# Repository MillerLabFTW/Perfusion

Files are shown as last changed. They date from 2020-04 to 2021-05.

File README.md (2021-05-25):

# Perfusion
### Open-source design for perfusion chambers and related accessories
#### Miller Lab: Physiologic Systems Engineering and Advanced Materials
#### [millerlab.rice.edu](http://millerlab.rice.edu)
###### Project developed by Ian Kinstlinger; revised 04/2020

This repo contains open-source designs for our customizable perfusion chamber system, as detailed in our [2021 paper in Nature Protocols](https://rdcu.be/clcY7). We have included some useful accessories as well which we encourage you to download and print. Please also check out the separate git repo for our [open-source gel flipper](https://github.com/MillerLabFTW/GelFlipper).

To generate perfusion chambers, you will need to first download [OpenSCAD](https://openscad.org/). Our paper linked above provides instructions for programming the chamber design you want, and then subsequently assembling the physical chamber for perfusion experiments. If you want to explore the more advanced functionality of the script for making multiple sets of ports, we have a tutorial for that in the Nature Protocols supplement, also included in this repo for convenience. 

**Bugs and feature requests:** Please help us optimize the chamber design by reporting any bugs you might encounter. Email ian.kinstlinger [at] gmail [dot] com. We may also be able to advise you if you want to add a feature which is not currently supported. We encourage everyone to remix and expand these tools and we would love to see new versions created by the community.

**How to cite:** If you use these resources in a publication, please cite this project as

Kinstlinger, I.S., Calderon, G.A., Royse, M.K. et al. Perfusion and endothelialization of engineered tissues with patterned vascular networks. Nat Protoc (2021). https://doi.org/10.1038/s41596-021-00533-1

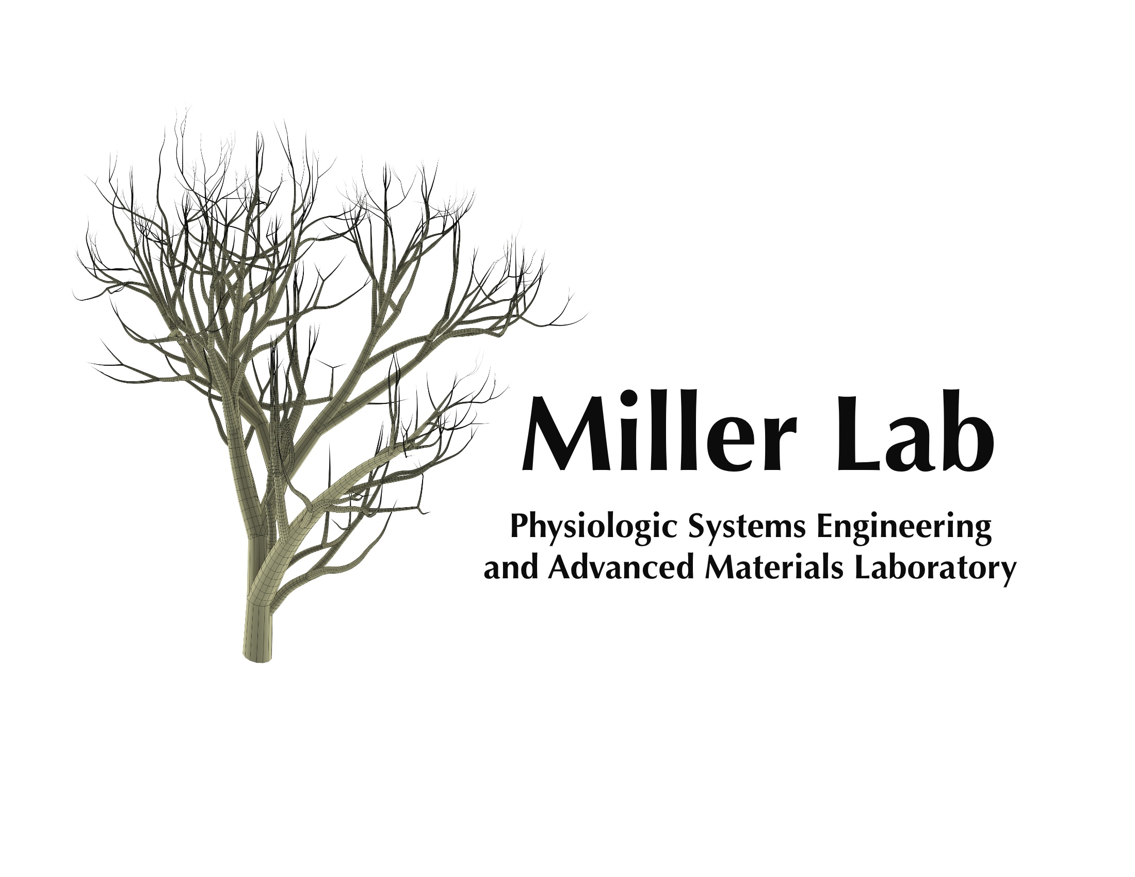
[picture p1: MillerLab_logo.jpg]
MillerLab logo


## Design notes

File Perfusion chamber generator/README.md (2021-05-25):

## Perfusion chamber generator

This is the core OpenSCAD file for generating 3D printable perfusion chambers. Please see detailed instructions in our [Nature Protocols paper](https://rdcu.be/clcY7).

Note 1: Make sure you save the Tip.stl files in the same directory as the .scad file so that the boolean operations work in OpenSCAD!

Note 2: If the Luer tip sizes do not print correctly on your printer, look at the Luer Tip Calibration folder.

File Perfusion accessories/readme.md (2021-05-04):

## Some useful 3D printed accessories for perfusion culture
### Ready-to-print STL files and editable design files provided for each item

### - Offset stands for perfusion chambers
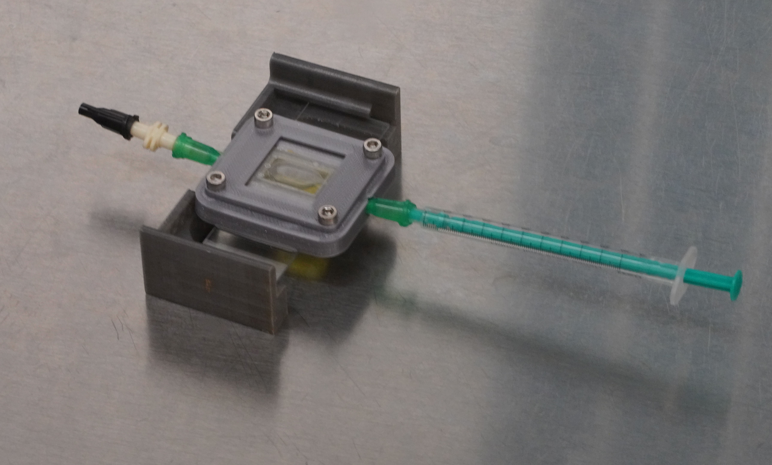
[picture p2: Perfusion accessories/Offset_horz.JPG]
Offset

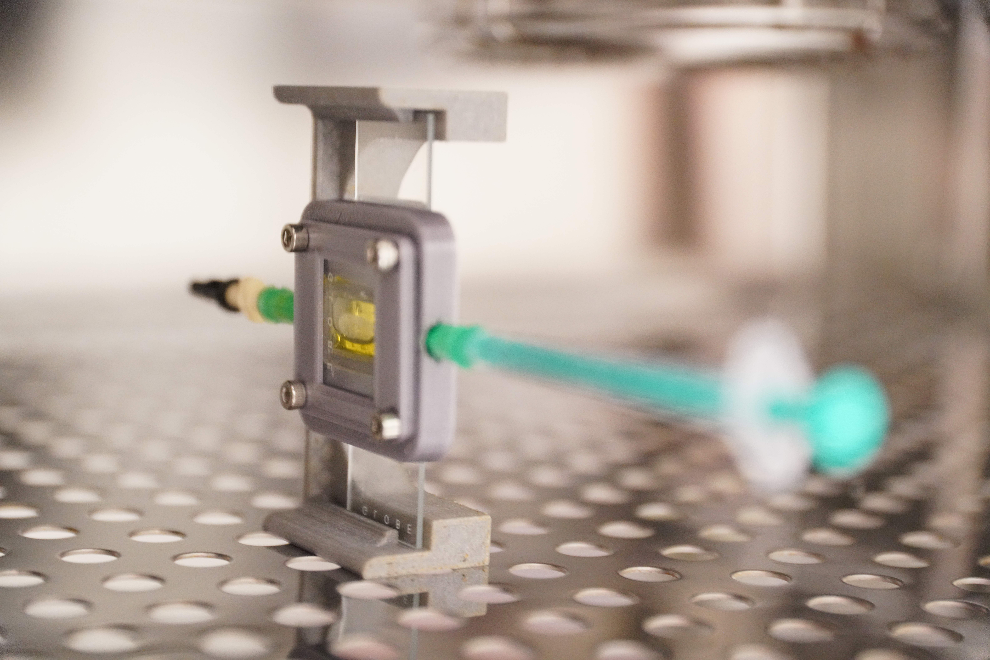
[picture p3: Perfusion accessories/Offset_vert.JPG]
Offset2


This is a simple stand for our perfusion chamber design which positions the inlet of a thin gel high enough above the bench/shelf to connect a sterile filter upstream. The design also makes it easy to handle and transport the chambers, and to rotate them around for endo seeding.

### - Vertical gel stand
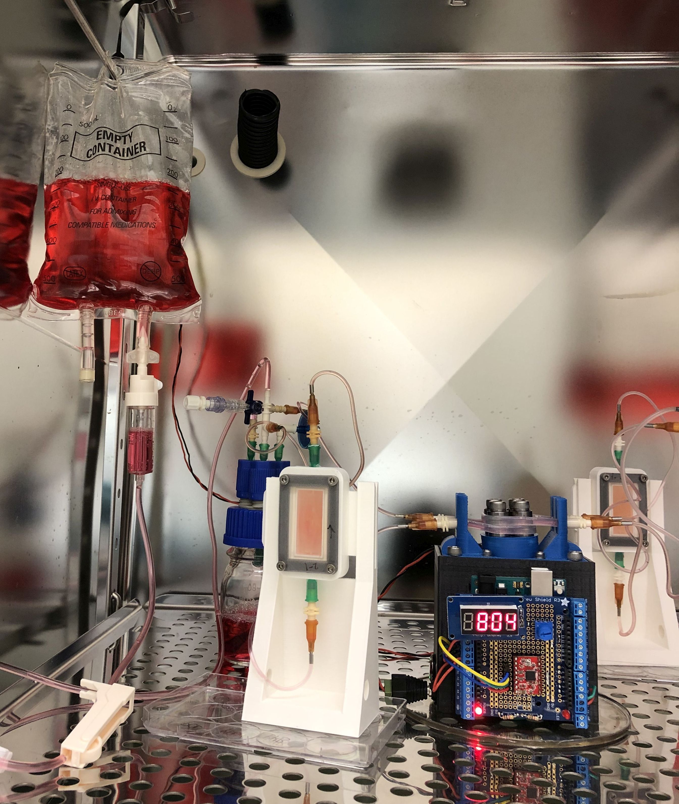
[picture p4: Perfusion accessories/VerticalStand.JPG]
Vert stand


Vertical perfusion can give more even fluid transport through gels with highly branched vascular networks. This vertical stand fits our perfusion chamber design if the "fins" option is enabled.

### - Media bag hanging racks

We have built custom media bag racks from aluminum T-slot extrusion (available from Misumi or McMaster-Carr, and others). The design depends on the model of incubator where you need to install it. We have one incubator with solid shelves and perforated walls, where we use rack that mounts to the wall. 

Many incubators have perforated shelves, for which we make a standing rack out of three pieces of extrusion in a U shape (hold together with corner brackets). To mount, we have feet which can be inserted into the shelf perforations. 

The two designs given here may not fit your incubator exactly, but hopefully will give you an idea of what can work.

Parts list for rack:
- 20x20 mm T-slot aluminum extrusions (e.g. McMaster-Carr 5537T514)
- Corner brackets for 20mm T-slot extrusion (e.g. McMaster-Carr 5537T441)
Some brackets come with fasteners. If you need separate fasteners:
- M5 T-slot nuts (e.g. McMaster-Carr 90510A232)
- M5x8 mm bolts (e.g. McMaster-Carr 91292A191)

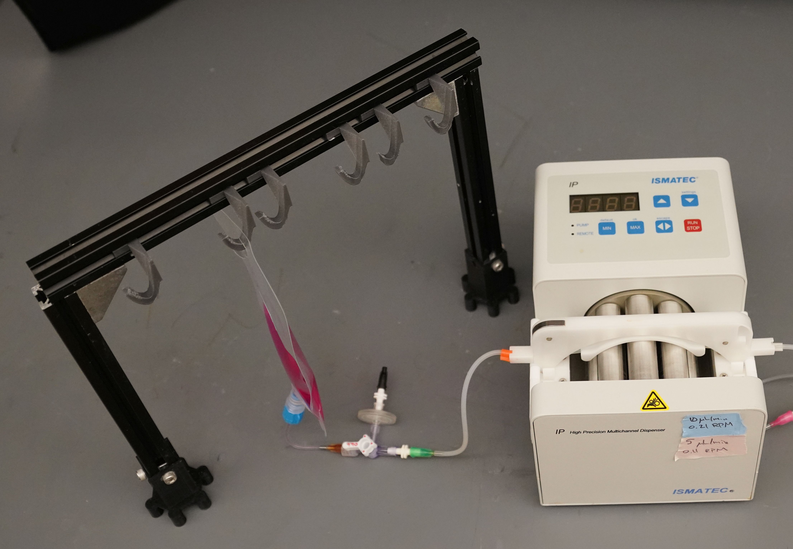
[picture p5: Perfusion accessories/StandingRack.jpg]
StandingRack


How the rack's feet can be mounted in an incubator:
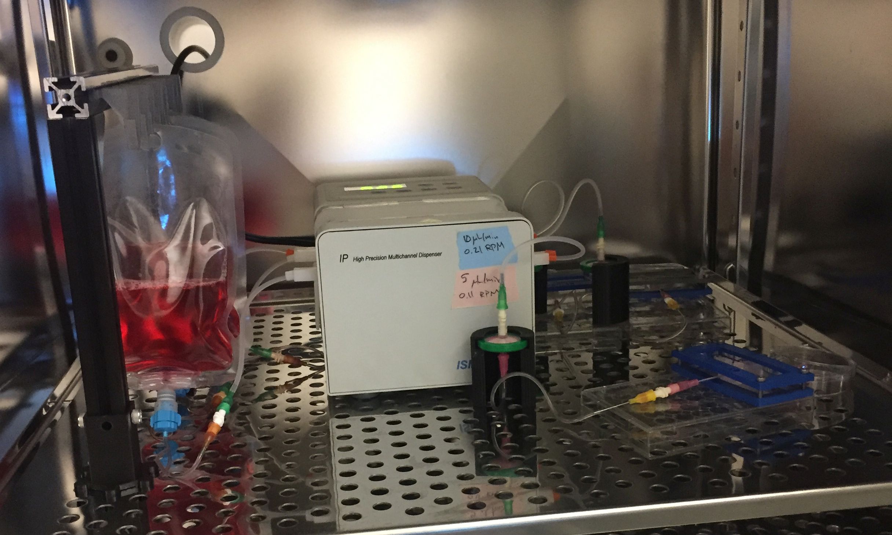
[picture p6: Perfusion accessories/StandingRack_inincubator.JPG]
StandingRack


Hanging version; feet insert into wall:
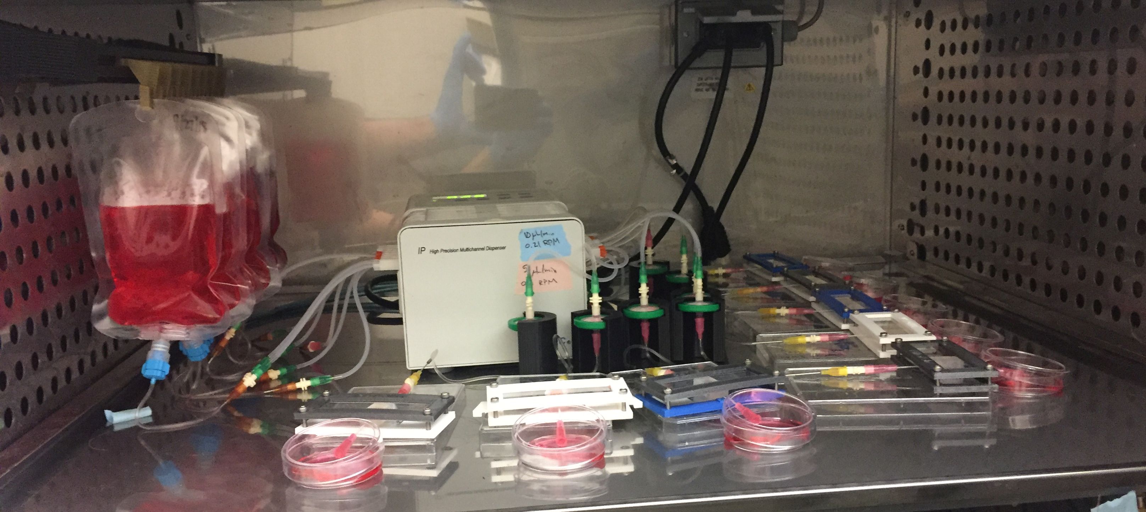
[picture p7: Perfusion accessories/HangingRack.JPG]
HangingRack


### - Media bag hanging hooks

A hanging rack isn't much use without hooks! We have a simple 3D printed hook design which can slide along the tracks of the T-slot extrusion, pictured above.

### - Microscope adapters for imaging perfusion chambers

We include one adapter for a standard multiwell plate format which should fit any standard microscope with a plate imaging stage. We also include a larger adapter for the entire stage footprint of a Nikon Ti-E inverted microscope. With the provided SolidWorks files, this can be modified to fit other brands of microscopes.

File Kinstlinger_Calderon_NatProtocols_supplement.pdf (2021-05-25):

# Supplementary information

# Perfusion and endothelialization of

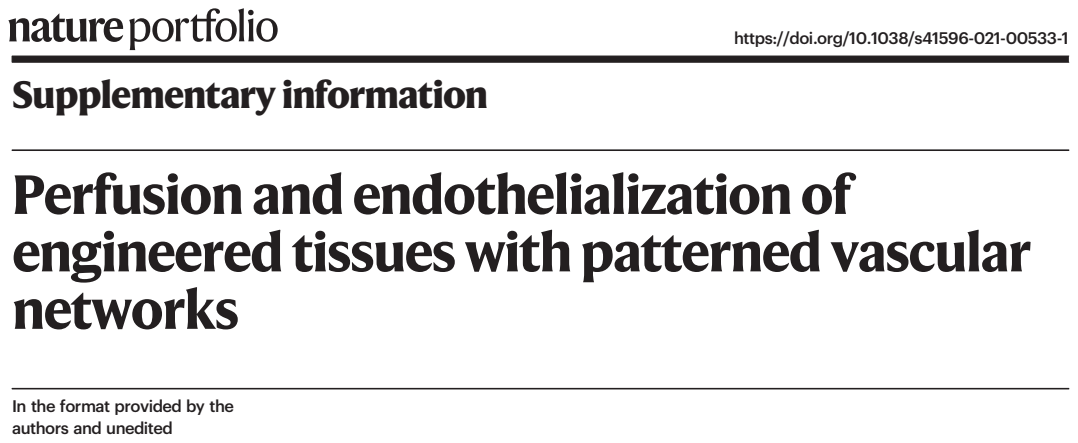
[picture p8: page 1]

https://doi.org/10.1038/s41596-021-00533-1

engineered tissues with patterned vascular
networks

In the format provided by the
authors and unedited

### Supplementary information for

### Perfusion and endothelialization of engineered tissues with patterned vascular networks

Ian S. Kinstlinger¹*, Gisele A. Calderon¹*, Madison K. Royse¹

, A. Kristen Means¹
,

Bagrat Grigoryan¹

, and Jordan S. Miller¹†

1 Department of Bioengineering, Rice University, Houston, TX, USA

* Authors contributed equally

† Corresponding author, email: jmil@rice.edu

Supplementary Manual: Customization of perfusion chambers with multiple sets of inlets and outlets

In the main manuscript, we outline how our scriptable perfusion chambers can be easily modified to accommodate gels of various dimensions or incorporate additional features such as PDMS anchors and gaskets. Here we describe a more advanced set of options to specify the positions of an arbitrary number of ports for catheterizing the gel. These options are useful for changing the position of the default single inlet and single outlet, and also for adding new sets of ports which may facilitate experiments with multivascular networks or side-by-side configurations of perfusable channels.

The nomenclature for specifying port locations relies on an openSCAD variable called portsVector. portsVector is a vector of vectors and is declared between lines 88-98 of the R2 version of the perfusion chamber generator script. By default, the definition of portsVector is:

PortsVector = [

[0, 0, 0, TipBooleanDist, NeedleGauge, 1]

];

Generating a chamber with this default portsVector results in the placement of a single inlet and single outlet on the short sides of the chamber (Fig. 1a). Each port is exactly centered on its face in the default configuration. Note that TipBooleanDist and NeedleGauge are user-defined parameters in the code, which have default values of 11 and 18 (GA), respectively.

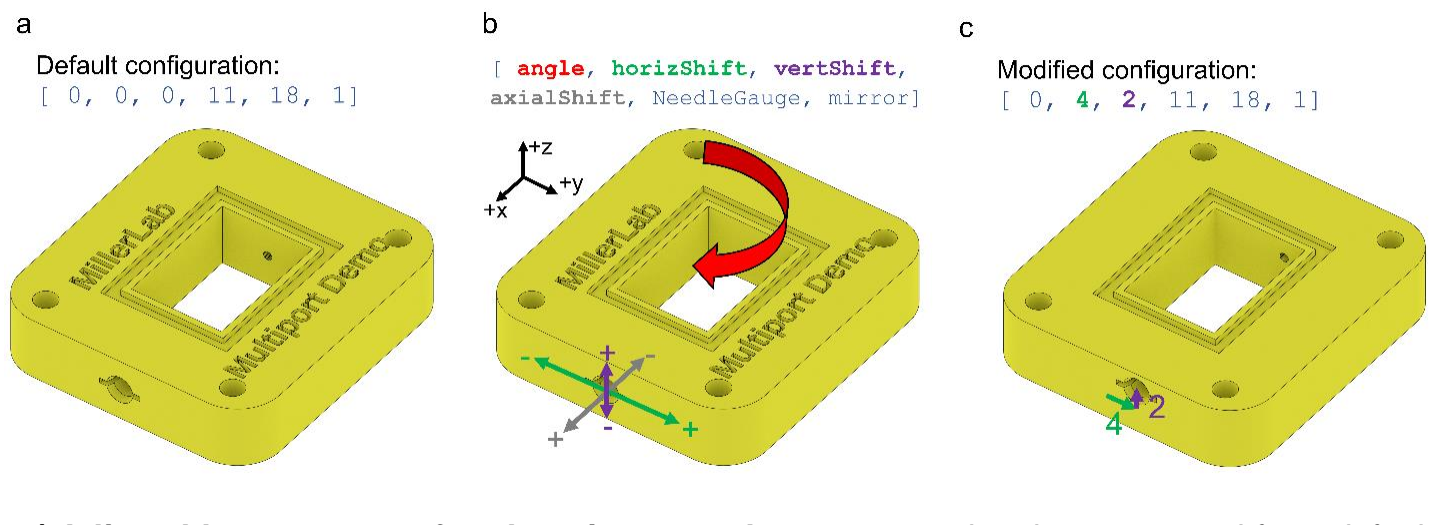
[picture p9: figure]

Figure 1 | Adjustable parameters for changing port placement. a, chamber generated from default
portsVector settings. b, Annotation of rotation and translation functions available for port placement. c, Annotated example of translating an inlet/outlet port pair to an off-center position.

We can begin to understand the syntax for generating custom ports by adjusting the vector elements in the default port. Each vector within PortsVector has six elements which specify the geometry of the tip, as described below:

PortsVector = [

[ angle, horizShift, vertShift, axialShift, NeedleGauge, mirror]

];

Fig. 1b illustrates the effect of the first four elements in terms of the inlet position. Fig. 1c demonstrates the translation of the inlet port by altering elements 2 and 3, horizShift and
vertShift.

Adjust element 1 to change which side of the chamber the port is added on. The default position is 0 degrees, which corresponds to short side in the -x direction. Use 90 degrees to get a port placed on the long side (in the -y direction). 180 gives a port on the short side in the +x direction, and so on. Values of element 1 not in 90 degree increments are allowed, but should only be used in the rare case that the vascular network itself does not form a right angle with respect to the gel. Fig. 2 provides a visual recap of the angle selection. Note: when combining an angle setting with a horizShift, note that the direction of the horizontal shift will always be in the +x or +y direction.

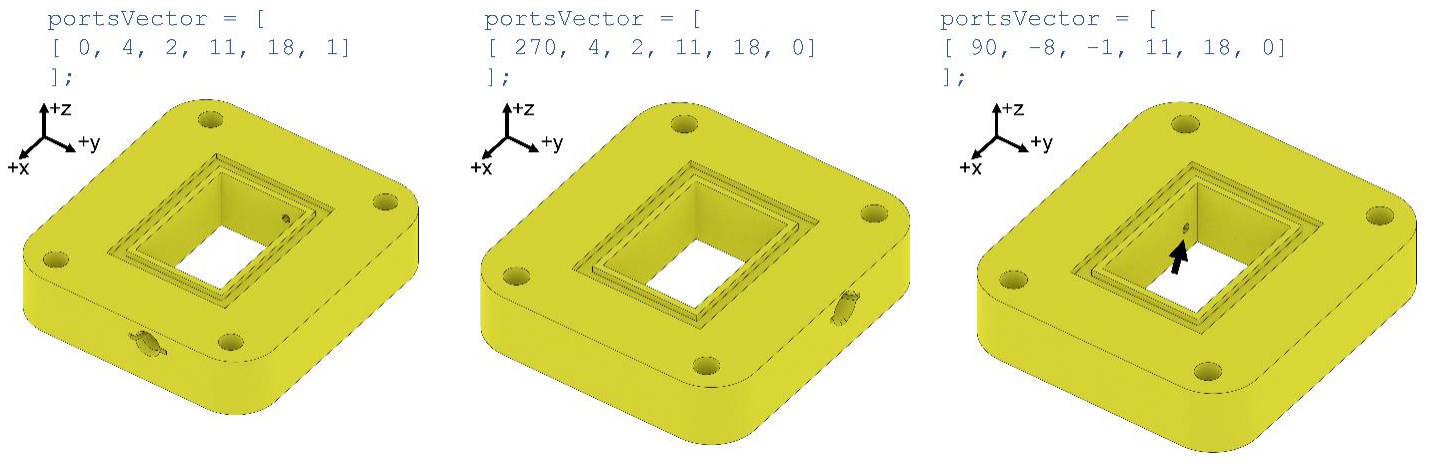
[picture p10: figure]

Figure 2 | Rotation angle parameter for port placement. Examples highlight the effects of adjusting
element 1 in portsVector to describe the face where the port is placed.

Element 4, axialShift, controls where the cavity for the catheter tip is positioned relative to the chamber edge. This has the effect of controlling how far the tip will protrude into the chamber interior, and thus, into the gel. The correct value will depend on your catheter tip length and how far you want it to stick into the inlet. A larger value of axial shift will push the catheter tip out of the central cavity; a smaller value will make it stick further into the gel (see Fig. 3a). By default, axialShift is set to the openSCAD variable TipBooleanDist, which has default value is 11, an empirically determined value which has worked well in our studies.

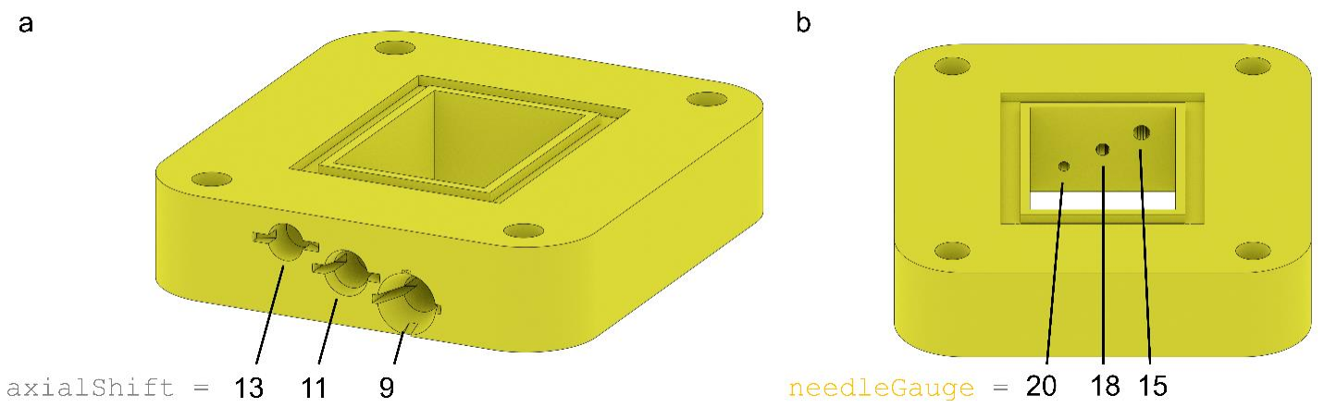
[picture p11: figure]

Figure 3 | Axial port positioning and tip diameter. a, Three example ports demonstrate the effect of
the axialShift parameter on the geometry of the cavity where the Luer tip is wedged into the chamber. b, An array of three ports highlights the three Luer tip port sizes available by default within the perfusion generator script, selected with needleGauge.

Element 5, needleGauge, is simply the gauge of catheter tip you want to insert through the port. 15, 18, and 20 gauge needles have been optimized extensively within the code and are the pre-loaded size options (Fig. 3b). The default is 18 gauge.

Element 6, mirror, allows you to use a single entry in portsVector to define not a single port, but a pair of ports, e.g. an inlet and outlet. For a tip geometry described by portsVector elements 1-5, mirror specifies the number of axes across which the port should be reflected. mirror can be assigned the value 0, 1, 2, or 3, the effects of which are shown in Fig. 4. mirror = 0 creates just one port, mirror > 0 creates a pair of ports by reflecting the specified port across 1, 2, or 3 axes. The first axis of reflection always places the reflected port on the opposite side of the chamber; the second and third axes reflect the port horizontally and vertically across the same side of the chamber.

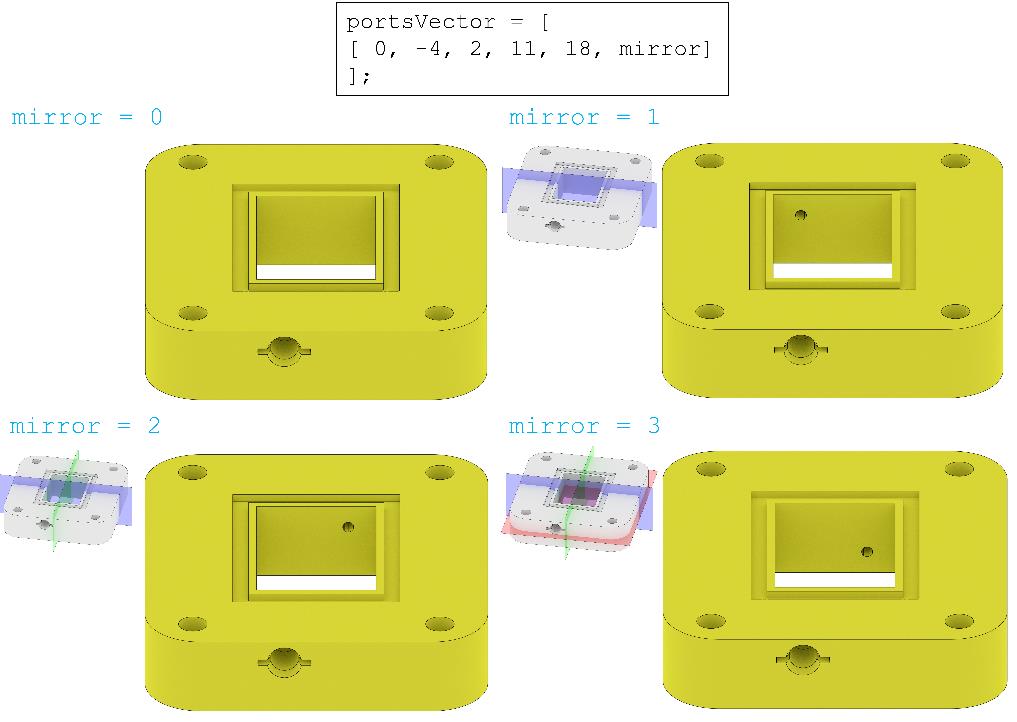
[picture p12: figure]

Figure 4 | Mirroring tips to create pairs of inlets/outlets. The resulting geometry is shown for each
possible value of mirror applied to the same base port configuration. Chambers are viewed from the -x direction.

Now that we have described how the 6 elements of each vector entry in portsVector can be used to control port placement, we can begin adding multiple sets of ports by adding additional vectors within portsVector. Fig. 5 shows some examples which combine sets of ports. Note that vectors within portsVector must be comma-separated, and that lines of code within openSCAD can be commented out with a // to suppress them.

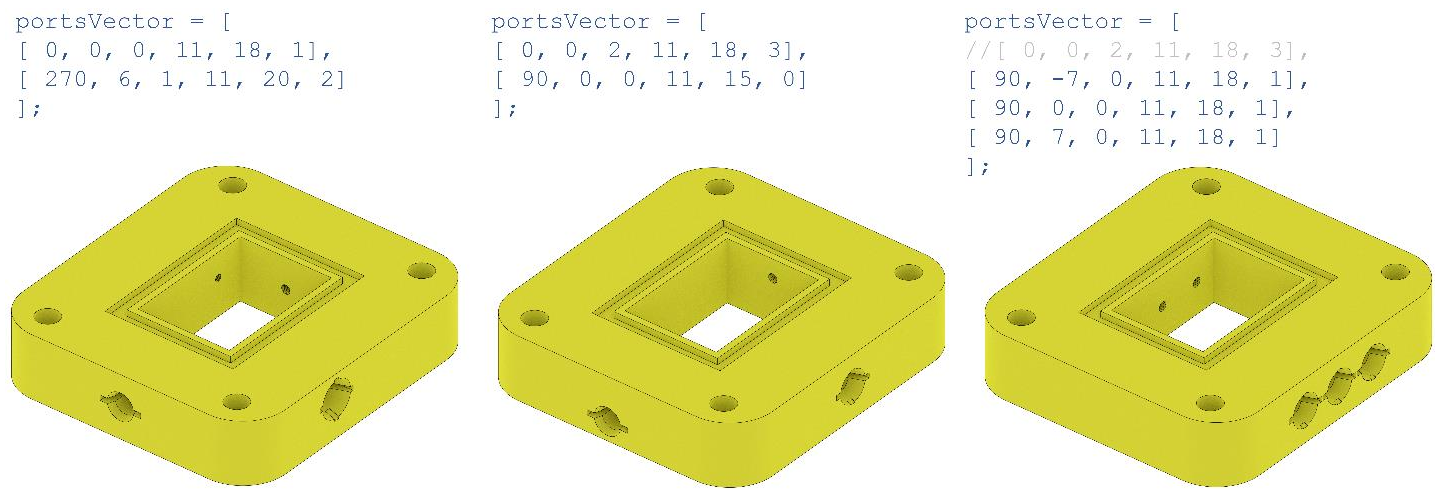
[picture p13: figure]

Figure 5 | Examples of configurations with multiple ports. We illustrate examples with 4, 3, and 6
total inlet/outlet ports to highlight the flexible configurations available.

Finally, we note that the other features of the perfusion chamber generator are fully compatible with the repositioning and addition of ports. In particular, if needle gaskets and PDMS anchor traps are enabled, these features will be automatically repositioned as needed when ports are relocated. We demonstrate these features in Fig. 6.

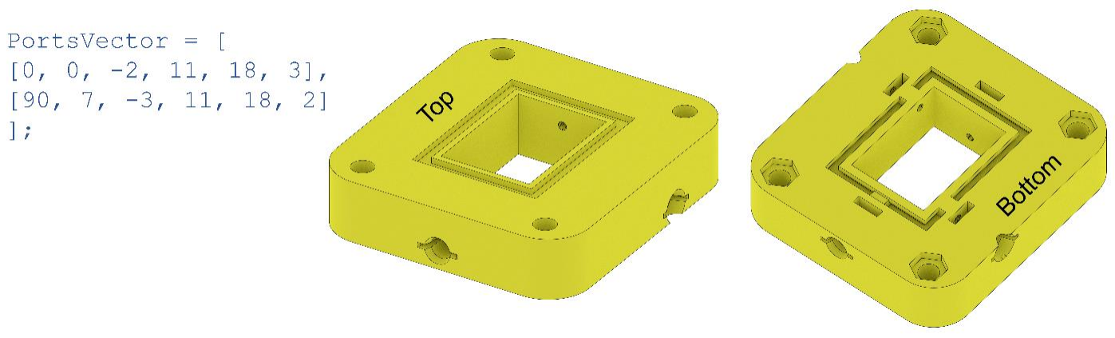
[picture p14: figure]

Figure 6 | PDMS trap features adapted to reconfigured ports. In this example, needle molds and
PDMS anchor traps are enabled to create a stronger and longer-lasting airtight seal (see Fig. 2 in main Protocol). Note that when ports are added or rearranged, the needle molds follow the positions of the ports. As needed, a gap is created in the PDMS anchor trap perimeter for a Luer tip to pass through.

Supplementary figures

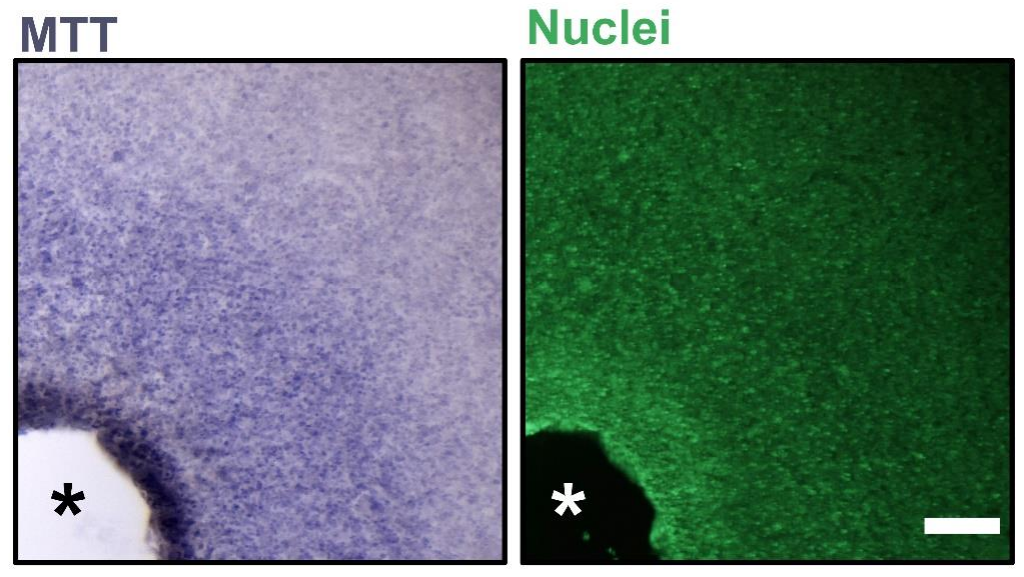
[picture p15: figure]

Figure S1 | Radial gradients of metabolic activity and cell density form around a perfused vessel.
In an initially homogeneous population of HepG2 cells (ATCC Cat# HB-8065, RRID:CVCL_0027; 60e6 cell/mL), we observed the development of radially inhomogeneous patterns of metabolic activity (MTT stain) and proliferation (using nuclear intensity as a proxy for number of cells) after three days of perfusion (25 µL/min) using the protocols described in stages 1 and 3. The methods used and the quantification and analysis of these gradient patterns are fully described in our previous publication¹
. Scale bar = 200
μm; gels are 2 wt% low-melt agarose; asterisk marks the lumen. Images were obtained using a SteREO Discovery.V8 stereoscopic microscope (Zeiss) equipped with EOS 5DSR color camera (Canon).

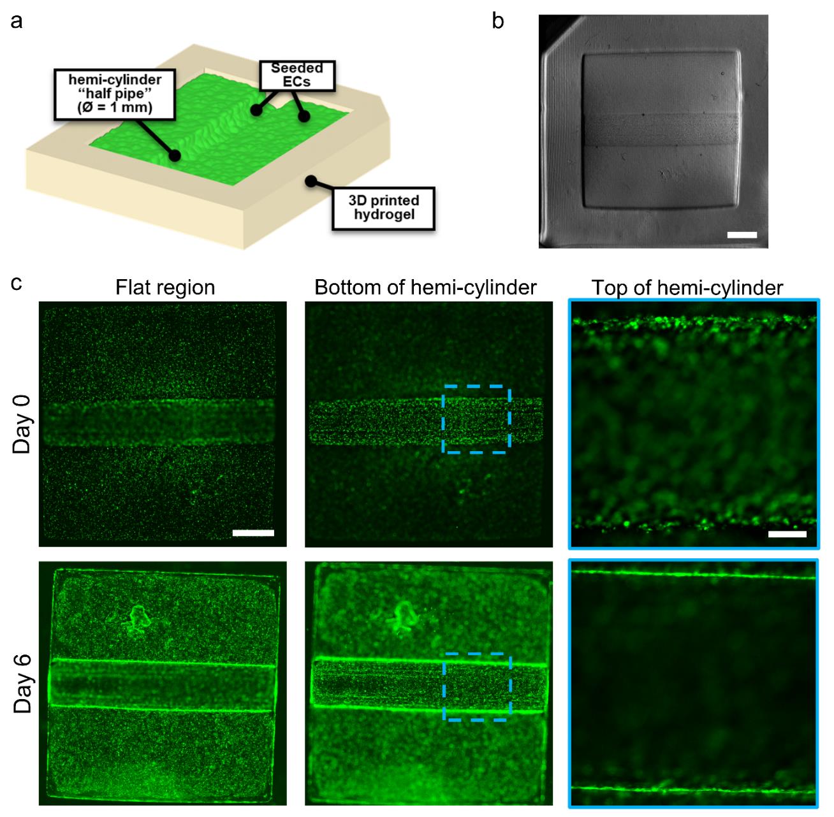
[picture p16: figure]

Figure S2 | Endothelial cell seeding on hemi-cylinders. a, We employ a “half-pipe” hydrogel as a 2.5D
model for endothelial cell attachment to patterned hydrogels. The half-pipe architecture includes curved and flat regions to evaluate the adhesion and morphology of ECs in each topology. b, Here, half-pipe models were printed via hydrogel stereolithography from 10 wt% GelMA mixed with 3.25 wt% PEGDA (3.4 kDa). GFP-HUVEC cells were seeded over 4 h at a density of 400 × 10³ cell cm⁻²
, which was
calculated as equivalent to our suggested cell density of 30 × 10⁶ cell ml⁻¹
for injection into hydrogel vascular networks. Scale bar = 1 mm. c, Longitudinal epifluorescence images show effective adhesion of HUVECs to the flat and curved regions of the half-pipe. Magnified view of the top of the hemi-cylinder shows that initially rounded cells (Day 0) adopt a spread morphology over 6 days in culture. Gels were gently washed with PBS on Day 0 to remove unadhered cells prior to imaging. Images were acquired on a Ti-E epifluorescence microscope (Nikon) equipped with Zyla 4.2 sCMOS camera (Andor). Scale bars = 1 mm (low magnification); 200 µm (high magnification).

References in supplementary information

1. Kinstlinger, I. S. et al. Generation of model tissues with dendritic vascular networks via sacrificial laser-sintered carbohydrate templates. Nat. Biomed. Eng. (2020) doi:10.1038/s41551-020-0566-1

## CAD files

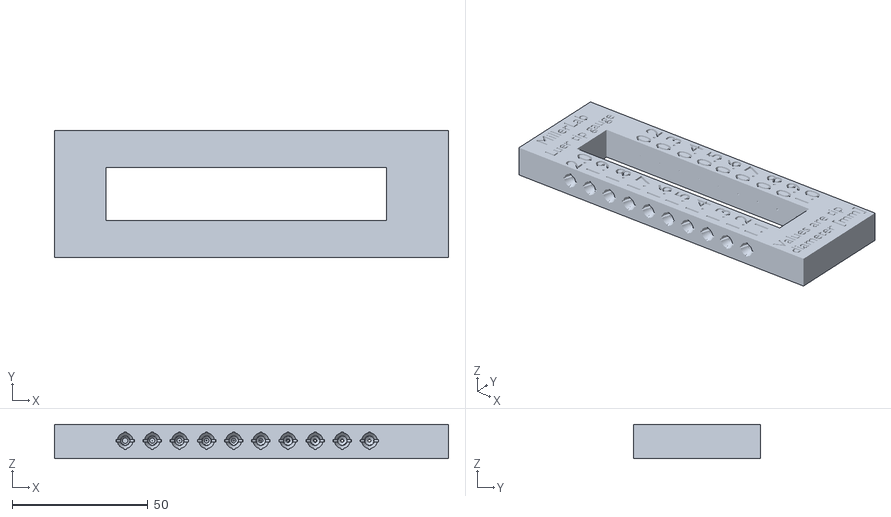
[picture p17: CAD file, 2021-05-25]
Luer tip calibration/LuerTipGauge.stl
145.1 x 46.7 x 12.6

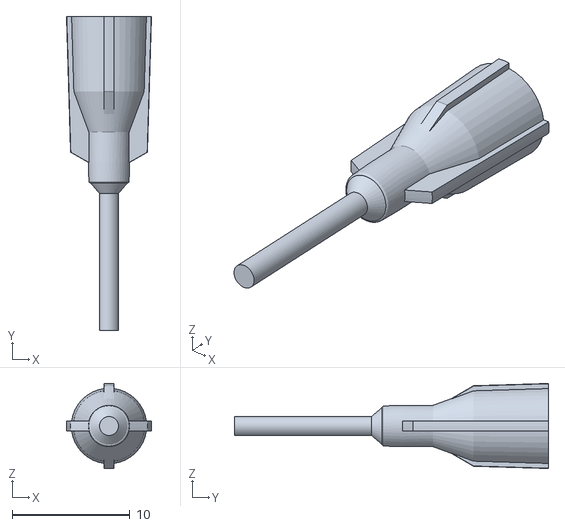
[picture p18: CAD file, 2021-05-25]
Luer tip calibration/Tip STLs/1.6.stl
7.23 x 26.7 x 7.23

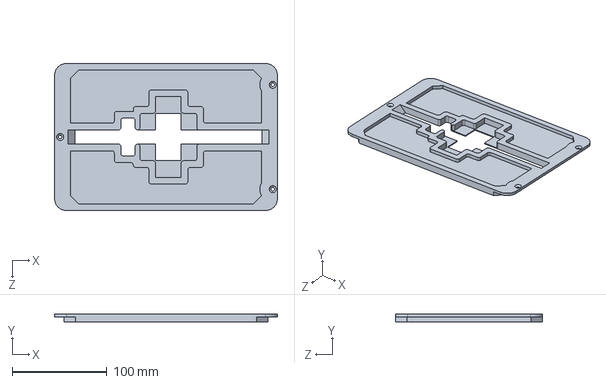
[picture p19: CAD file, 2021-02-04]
Perfusion accessories/MicroscopeAdapter__Nikon.SLDPRT
235.0 x 8.00 x 155.0 mm

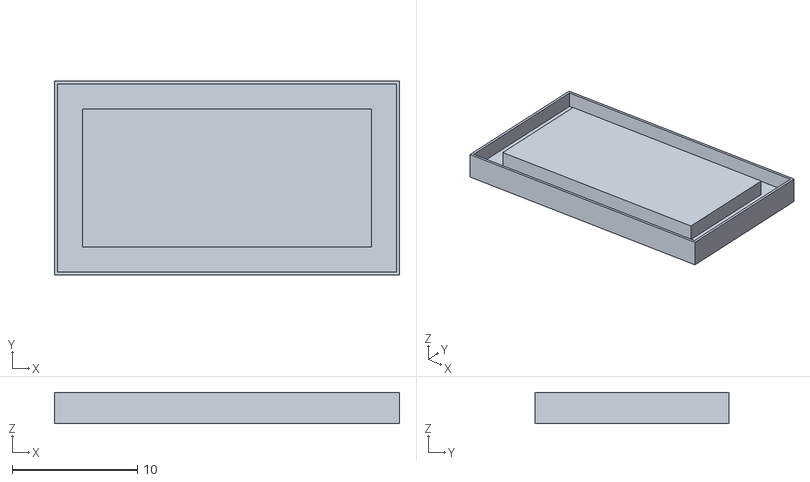
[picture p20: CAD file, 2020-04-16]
Perfusion chamber generator/Example chamber STL files/Demo_GasketLid.stl
27.5 x 15.5 x 2.50

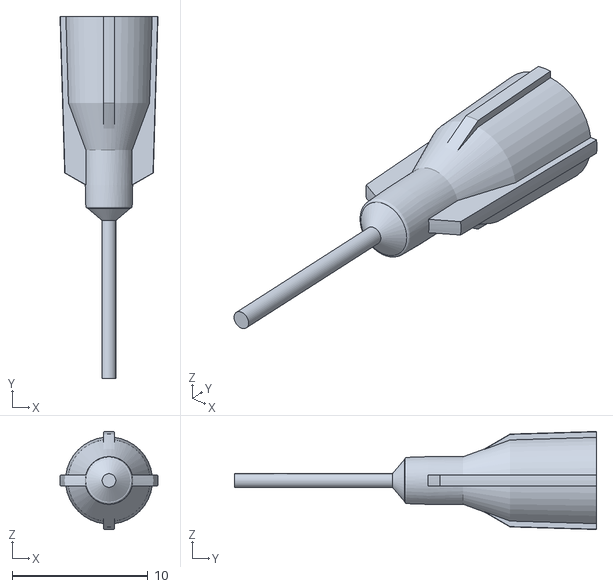
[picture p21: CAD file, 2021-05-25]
Luer tip calibration/Tip STLs/1.0.stl
7.23 x 26.7 x 7.23

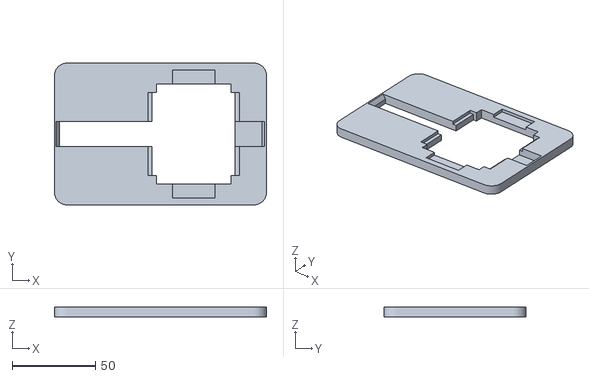
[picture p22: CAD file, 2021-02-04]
Perfusion accessories/MicroscopeAdapter_wellPlate.stl
127.7 x 85.4 x 6.00

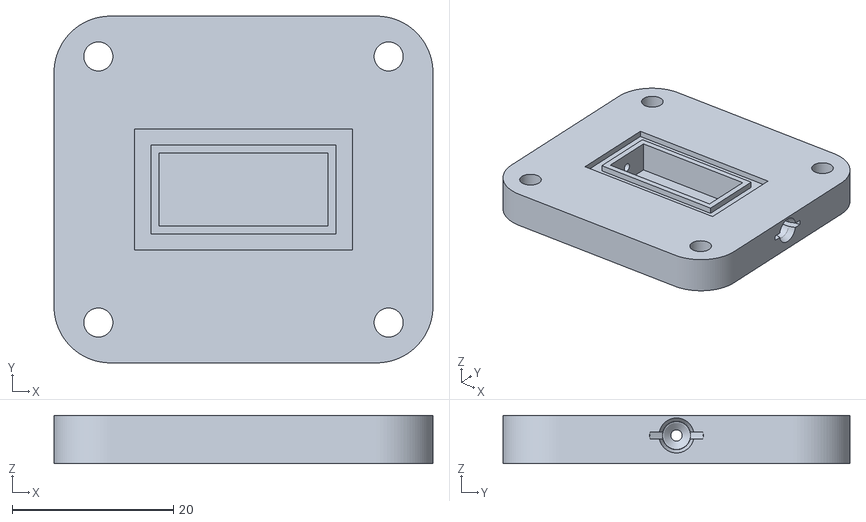
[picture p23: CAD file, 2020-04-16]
Perfusion chamber generator/Example chamber STL files/Demo_Chamber_SolidBottom.stl
47.0 x 43.0 x 6.00

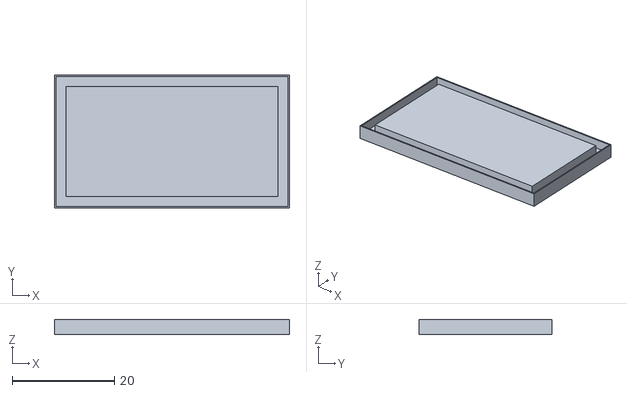
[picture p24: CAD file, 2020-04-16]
Perfusion chamber generator/Example chamber STL files/Demo_Large chamber/GasketMold.stl
46.0 x 26.0 x 3.00

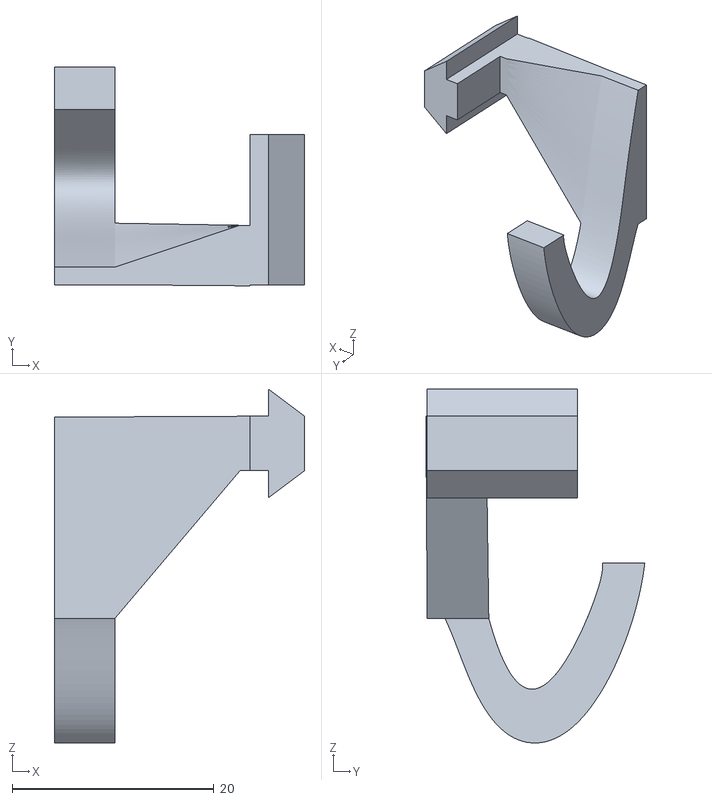
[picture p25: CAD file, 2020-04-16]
Perfusion accessories/Hook_TSlotExtrusion.stl
24.8 x 21.7 x 35.1

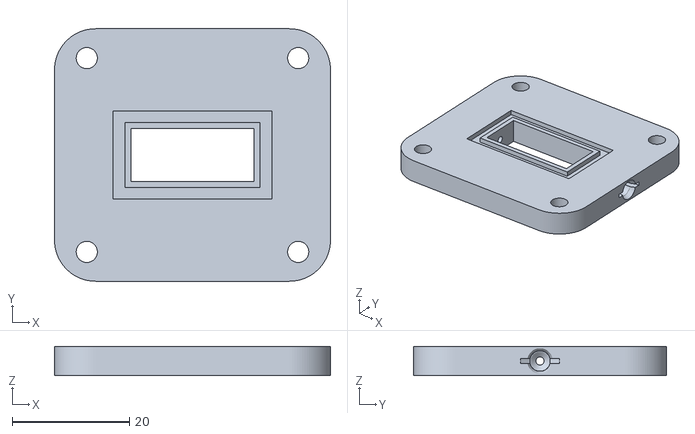
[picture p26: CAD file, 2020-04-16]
Perfusion chamber generator/Example chamber STL files/Demo_Chamber_OpenBottom.stl
47.0 x 43.0 x 5.00

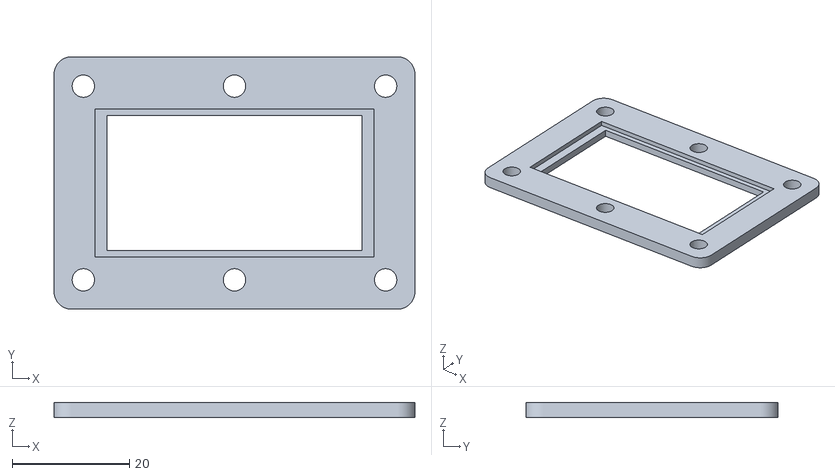
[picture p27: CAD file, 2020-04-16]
Perfusion chamber generator/Example chamber STL files/Demo_Large chamber/Lid.stl
61.5 x 43.0 x 2.50

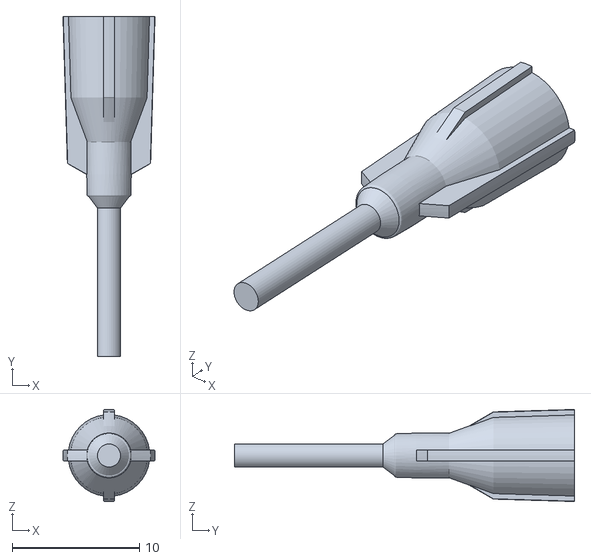
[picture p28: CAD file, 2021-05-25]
Luer tip calibration/Tip STLs/1.8.stl
7.23 x 26.7 x 7.23

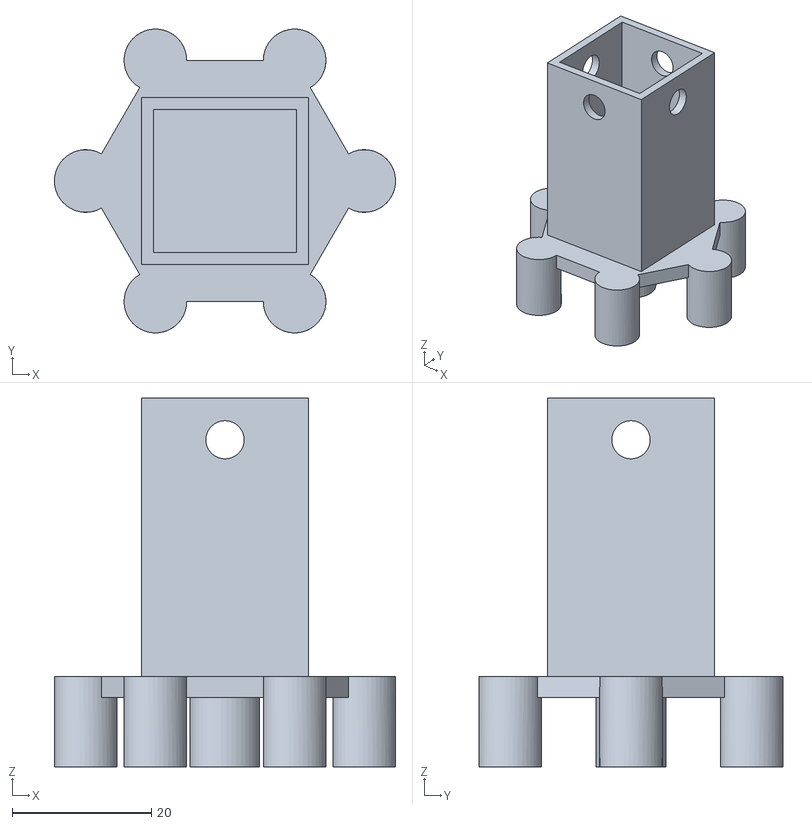
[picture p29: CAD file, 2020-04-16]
Perfusion accessories/ExtrusionRack_Feet_standing_version.stl
49.0 x 43.6 x 53.0

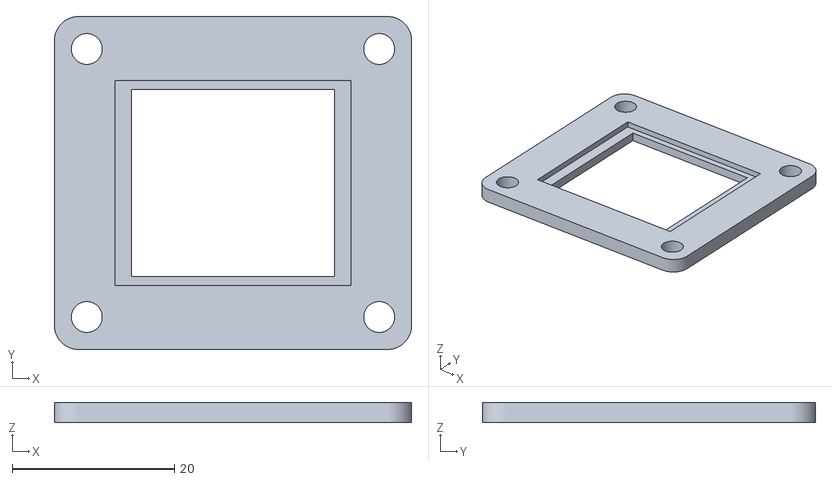
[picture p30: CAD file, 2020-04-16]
Perfusion chamber generator/Example chamber STL files/Demo_Lid.stl
44.0 x 41.0 x 2.50

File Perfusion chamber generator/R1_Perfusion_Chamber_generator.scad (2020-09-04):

//************************************//
//************************************//
//    Perfusion Chamber Generator     //
//    Ian Kinstlinger, MillerLab      //
//    Updated 9/2/2020               //
//************************************//
//************************************//

//////////////////////////////////////
//Gel dimensions
//////////////////////////////////////

GelLength = 19; //mm
//The script will automatically make the chamber 2mm longer than the gel to give clearance for catheters and repositioning
GelWidth = 9; //mm
GelHeight = 10; //mm

nameText1 = "Hello World";
nameText2 = "Chamber Body";
// Optionally add engraved text to label your model
// **Make sure the name is short enough to fit on the chamber**
// There is no coded length limit because the limit depends on chamber size
// For no engraved text, leave empty quotes

////////////////////////////////////////
//What component to generate? Only one should be enabled at a time!
////////////////////////////////////////

GenerateBody = 1;
GenerateGasketMold = 0;
GenerateLid = 0;

//ONLY turn one on at a time

///////////////////////////////////////////////
//Perfusion chamber style; 0 for no, 1 for yes
///////////////////////////////////////////////

Fins = 0 ; //To mount in a vertical holder
SolidBottom = 0; //Choose no (0) if you need to image through the bottom!
PDMSTraps = 1; //To add features to help with PDMS adhesion for glass slides
//NOTES: if making a solid bottom, PDMS traps should be off (no glass to adhere)
// Currently PDMS traps are not supported if extra screws are used
NeedlePDMS = 1; //Add empty space to create a PDMS gasket for your catheter tips
ExtraScrews = 0;
ExternalGelPorts =  0; //Add extra catheter ports on sides to allow media perfusion through external space on top of gel 


//*************************************
//Parameters you may want to change
//*************************************

InletOutletZOffset = 0; 
//If the inlet and outlet are not at the center of their respective faces of the gel, what is their offset? If lower then center, use a negative offset

NeedleGauge = 18; //Must be 15, 18, or 20!
//By default, all tips assumed to be the same gauge. More options below if not the case

TroughWidth = 2; //How wide is the trough which holds the PDMS gasket?
TroughDepth = 1; //How deep is the trough which holds the PDMS gasket?

xScrewOffset = 8.5; //Spacing screws along gel long side
yScrewOffset = 3; //Spacing screws along gel short side

GasketHeight = 1.5;
LidHeight = 2.5; //mm


//*************************************
//Parameters that should mostly stay the same
//*************************************

ExternalPortZOffset = 3.5; //Position above center for extra catheter ports

ChamberHeightOffset = 0 + ExternalGelPorts*(ExternalPortZOffset+0.5); //Changes the overall height of the chamber without affecting gel chamber placement or dimensions
    //Note: ChamberHeightOffset must be increased (recommended +0.5 of MediaPortZOffset) if using media ports to allow room for needles without interfering with PDMS gasket

GelExtLength = GelLength + 2; //Add 2 mm to give space to maneuver and visualize catheters
InOutThick = 26; //mm //Adjust this to change how much the tip sticks into the gel channel
SpaceforScrews = 18; //mm //Width of solid region where the screws go through
TipBooleanDist = 11; //mm //This controls the gemetry of where the Nordson tip is wedged into the chamber

ExternalPortBooleanDist = 4; // //This controls the gemetry of where the optional external gel tip is wedged into the chamber

ExternalPortNeedleGauge = NeedleGauge; //Change if different gauge tips are used

HullCylRad = 7; //This controls the filleted corner curvature
SlideWidth = 25; //Standard microscope slide is 25mm

textSize = 3;

screwNutTolerance = 0.3;
lidTolerance = 0.25;


//********************************
//Below here the geometry is built
//********************************

$fn=100; //Sets the resolution of the geometry


if (GenerateBody==1){
    chamber();
}
if (GenerateLid==1){
    lid();
}
if (GenerateGasketMold == 1){
    gasketMold();
}
//

module chamber(){

difference(){
   
union(){
filletCorners();

if(Fins == 1){
    fins();
}
    
}

//Here come all the things are are subtracting from the initial solid block

translate([0,0,ChamberHeightOffset/2]) cube([GelExtLength, GelWidth, GelHeight+ChamberHeightOffset], center = true); //Main gel cavity

booleanCatheterTip(); //Slots for catheter tips
mirror([1,0,0]){booleanCatheterTip();};

//Optional media ports
if(ExternalGelPorts == 1){
translate([.35*GelExtLength,-ExternalPortBooleanDist,0]) booleanMediaPorts(); //Slots for catheter tips for media ports on sides
translate([-.35*GelExtLength,ExternalPortBooleanDist,0]) mirror([0,1,0]){booleanMediaPorts();};

translate([-.35*GelExtLength,0,0]) NeedlePDMSMediaPorts();

translate([.35*GelExtLength,0,0]) mirror([0,1,0]){NeedlePDMSMediaPorts();};


}

//Make the trough for the PDMS gasket
//2mm is hardcoded as the space between the gel chamber and the trough

difference(){
translate([0,0,(GelHeight-TroughDepth)/2+ChamberHeightOffset])cube([GelExtLength+2+TroughWidth*2, GelWidth+2+TroughWidth*2, TroughDepth], center = true);
    
translate([0,0,(GelHeight-TroughDepth)/2+ChamberHeightOffset])cube([GelExtLength+2, GelWidth+2, TroughDepth], center = true);
}



//PDMS traps
if(PDMSTraps == 1){
        PDMSTrap();
    mirror([0,1,0]){PDMSTrap();};
}

//Gaskets for catheters
if(NeedlePDMS == 1){
    NeedlePDMS();
    mirror([1,0,0]){NeedlePDMS();};
}

//Holes for screws and traps for nuts

screwsAndNuts();

labelText();

//translate([0,0,-GelHeight]) cube([5*GelExtLength,5*GelWidth,5*GelHeight], center = false); //uncomment this line to see the cross-section

} //end of difference() 



} //end of chamber module

module lid(){
    //translate([0,0,GelHeight/2 + LidHeight/2 + (GasketHeight-TroughDepth)])

difference(){

hull(){ //lid
    translate([xScrewOffset+GelExtLength/2+1, yScrewOffset+SlideWidth/2+1, 0]) cylinder(r = 3, h = LidHeight, center = true);
    translate([-xScrewOffset-GelExtLength/2-1, yScrewOffset+SlideWidth/2+1, 0]) cylinder(r = 3, h = LidHeight, center = true);
    translate([xScrewOffset+GelExtLength/2+1, -yScrewOffset-SlideWidth/2-1, 0]) cylinder(r = 3, h = LidHeight, center = true);
    translate([-xScrewOffset-GelExtLength/2-1, -yScrewOffset-SlideWidth/2-1, 0]) cylinder(r = 3, h = LidHeight, center = true);
    
}


//Make holes in lid for M3 screws

if(ExtraScrews == 0){

    for (xScrewDir = [-1,1]){
    for(yScrewDir = [-1, 1]){
            
    translate([xScrewDir*(xScrewOffset+GelExtLength/2), yScrewDir*(yScrewOffset+SlideWidth/2), 0]) cylinder(r = screwNutTolerance+1.5, h = 2*GelHeight, center = true);
        // 1.5mm is hardcoded as the radius of an M3 screw
        
    }
}
}


if(ExtraScrews == 1){

    for (xScrewDir = [-1,0,1]){
    for(yScrewDir = [-1, 1]){
            
    translate([xScrewDir*(xScrewOffset+GelExtLength/2), yScrewDir*(yScrewOffset+SlideWidth/2), 0]) cylinder(r = screwNutTolerance+1.5, h = 2*GelHeight, center = true);
        // 1.5mm is hardcoded as the radius of an M3 screw
        
    }
}
}

//Make the recessed area for the glass slide
translate([0,0,(LidHeight-1)/2]) cube([GelExtLength+8, SlideWidth+lidTolerance,1], center = true);

//Make an open region to see through the slide
cube([GelExtLength+4, SlideWidth-2,LidHeight], center = true);



} //end difference()



}

module gasketMold(){
    difference(){

cube([GelExtLength+6.5, GelWidth+6.5, GasketHeight+1], center = true);  

//cube([GelExtLength, GelWidth, GasketHeight+1], center = true);
    //This line can be uncommented if you are curing the PDMS gasket at room temp to print faster
    //But if curing at 60C, you need this inner plastic to prevent the mold from warping
    
//Boolean out the trough
//2mm hardcoded for gap between gel and trough    
    
difference(){
translate([0,0,.5])cube([GelExtLength+2+TroughWidth*2, GelWidth+2+TroughWidth*2, GasketHeight], center = true);
    
translate([0,0,.5])cube([GelExtLength+2, GelWidth+2, GasketHeight], center = true);
}
    
}
    
}
//

module booleanCatheterTip(){
  
  if(NeedleGauge == 15){  
    rotate([0, 0, 90]) translate([0,TipBooleanDist+GelExtLength/2,InletOutletZOffset]) import("15GATip.stl");
    
}  
  
    else if(NeedleGauge == 18){
    
    rotate([0, 0, 90]) translate([0,TipBooleanDist+GelExtLength/2,InletOutletZOffset]) import("18GATip.stl");
  
}

    else if(NeedleGauge == 20){
    
rotate([0, 0, 90]) translate([0,TipBooleanDist+GelExtLength/2,InletOutletZOffset]) import("20GATip.stl");
 
}
    
    else{
    
    echo("Enter a valid needle gauge");
    }
}
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

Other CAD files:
Luer tip calibration/Tip STLs/1.5.stl
Luer tip calibration/Tip STLs/0.3.stl
Perfusion accessories/VerticalPerfusionStand.stl
Perfusion chamber generator/Example chamber STL files/Demo_Chamber_OpenBottom+PDMSAnchors.stl
Perfusion chamber generator/R2_Perfusion_Chamber_generator.scad
Luer tip calibration/Tip STLs/0.2.stl
Luer tip calibration/Tip STLs/0.4.stl
Luer tip calibration/Tip STLs/0.5.stl
Luer tip calibration/Tip STLs/0.6.stl
Luer tip calibration/Tip STLs/0.7.stl
Luer tip calibration/Tip STLs/0.8.stl
Luer tip calibration/Tip STLs/0.85.stl
Luer tip calibration/Tip STLs/0.9.stl
Luer tip calibration/Tip STLs/1.1.stl
Luer tip calibration/Tip STLs/1.2.stl
Luer tip calibration/Tip STLs/1.3.stl
Luer tip calibration/Tip STLs/1.4.stl
Luer tip calibration/Tip STLs/1.7.stl
Luer tip calibration/Tip STLs/1.9.stl
Luer tip calibration/Tip STLs/2.0.stl
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

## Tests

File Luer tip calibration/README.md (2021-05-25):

### Luer tip calibration

In the perfusion chamber generator, we provide STL files named 15GATip, 18GATip, etc, which OpenSCAD will use to Boolean subtract a cavity for the physical Luer tip to slide into the chamber. These STL files were sized empirically based on what fit correctly in our chambers, printed on Prusa i3 printers with 0.15mm layer height. 

If you need different sizes than the defaults provided, or the defaults are not the right size when printed on your printer, you can use this Luer tip gauge to figure out the correct size. 

First, print LuerTipGauge.stl on the same printer and with the same slicing profile as you will use for perfusion chambers. The gauge has slots for different sized Luer tips, from 0.2-2.0 mm in 0.1mm increments. 

Next, once you identity the right size (in mm) for your need, you can find the corresponding STL file in the folder "Tip STLs". That STL file should be **renamed** in the format ##GATip.stl, and copied into the same directory as the chamber generator SCAD script. (If you use filenames not in this format, you will need to change the SCAD file to recognize the new name).

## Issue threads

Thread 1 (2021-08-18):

Could you provide the openSCAD or STL file for gel printing？

gzzwjhzxh, 2021-08-18:
Dear developer:
      I'm trying to use your protocol to build an infusion chamber. Could you provide a gel printed openSCAD or STL file so that I can quickly determine whether the perfusion chambers can work?
     Thank you in advance

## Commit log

2020-04-16 initial file add
    [Demo_Chamber_ExtraPorts.stl, Demo_Chamber_OpenBottom+PDMSAnchors.stl, Demo_Chamber_OpenBottom.stl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]
2020-04-16 Add tip.stl files
    [15GATip.stl, 18GATip.stl, 20GATip.stl]
2020-09-04 Bug fix in generator script
    [R1_Perfusion_Chamber_generator.scad]
2021-02-04 Update microscope adapters
    [MicroscopeAdapter__Nikon.SLDPRT, MicroscopeAdapter__Nikon.STL, MicroscopeAdapter_wellPlate.f3d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]
2021-05-04 Add R2 perf chamber script with support for multiple sets of inlets/outlets
    [R1_Perfusion_Chamber_generator.scad, R2_Perfusion_Chamber_generator.scad]
2021-05-06 More tip sizes for script
    [19GATip.stl, 25GATip.stl]
2021-05-25 Update with Nat Protocols paper info
    [0.2.stl, 0.3.stl, 0.4.stl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]
